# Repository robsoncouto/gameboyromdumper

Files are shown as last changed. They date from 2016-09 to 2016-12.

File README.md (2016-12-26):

# gbcart tool (in progress)
Tool for reading data from Game Boy cartridges or the Gameboy camera. The version in the first commits work(mar 2016), but I have started to clean the code, so the present version (dec 2016) is uncomplete. 
##Description
This is a project that I started in order to backup my Gameboy saves to the PC. It also dumps roms and Gameboy camera saves. All the process that lead to this program is detailed at www.dragaosemchama.com.br/?lang=en_us
##Hardware
Schematic and layout ealge files are available, the cartridge-PC interface board uses a atmega32 and a Gameboy Color cartridge socket. The socket was salvaged from a broken gameboy. The board is connected to a PC with a USB-serial ttl cable.
##Usage
The python script is used for reading saves, roms or the cartridge header. The microcontroller code was written for a Atmega32, but can be easily ported to other microcontrollers or architectures.
##Serial library
This code uses avr-uart library kindly shared by Andy Gock based on uart library code by Peter Fleury
https://github.com/andygock/avr-uart

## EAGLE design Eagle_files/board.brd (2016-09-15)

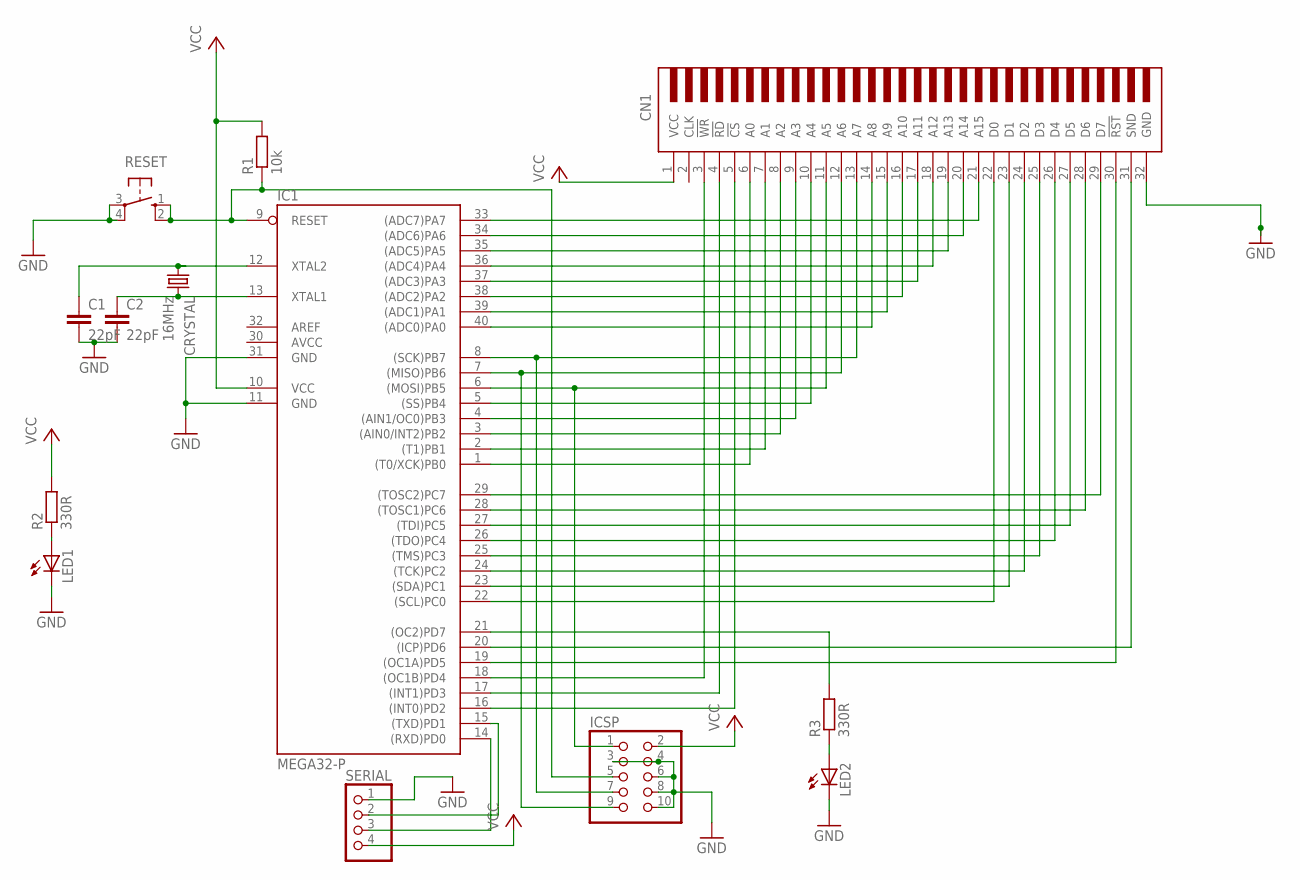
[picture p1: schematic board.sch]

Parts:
C1, C2: 22pF; C050-025X075
CN1: GBCONN
CRYSTAL: 16MHz; HC49/S
IC1: MEGA32-P; DIL40
ICSP: PINHD-2X5; 2X05
LED1, LED2: LED3MM
R1: 10k; 0204/7
R2, R3: 330R; 0204/7
RESET: 10-XX; B3F-10XX
SERIAL: PINHD-1X4/90; 1X04/90

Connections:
AVCC: IC1.30 (AVCC)
GND: C1.2, C2.2, CN1.32 (GND), IC1.11 (GND), IC1.31 (GND), ICSP.3, ICSP.4, ICSP.6, ICSP.8, ICSP.10, LED1.K (C), LED2.K (C), RESET.3, RESET.4 (P1), SERIAL.1
unnamed: CN1.29 (D7), IC1.29 ((TOSC2)PC7)
unnamed: CN1.28 (D6), IC1.28 ((TOSC1)PC6)
unnamed: CN1.27 (D5), IC1.27 ((TDI)PC5)
unnamed: CN1.26 (D4), IC1.26 ((TDO)PC4)
unnamed: CN1.25 (D3), IC1.25 ((TMS)PC3)
unnamed: CN1.24 (D2), IC1.24 ((TCK)PC2)
unnamed: CN1.23 (D1), IC1.23 ((SDA)PC1)
unnamed: CN1.22 (D0), IC1.22 ((SCL)PC0)
unnamed: CN1.21 (A15), IC1.33 ((ADC7)PA7)
unnamed: CN1.20 (A14), IC1.34 ((ADC6)PA6)
unnamed: CN1.19 (A13), IC1.35 ((ADC5)PA5)
unnamed: CN1.18 (A12), IC1.36 ((ADC4)PA4)
unnamed: CN1.17 (A11), IC1.37 ((ADC3)PA3)
unnamed: CN1.16 (A10), IC1.38 ((ADC2)PA2)
unnamed: CN1.15 (A9), IC1.39 ((ADC1)PA1)
unnamed: CN1.14 (A8), IC1.40 ((ADC0)PA0)
unnamed: CN1.13 (A7), IC1.8 ((SCK)PB7), ICSP.7
unnamed: CN1.12 (A6), IC1.7 ((MISO)PB6), ICSP.9
unnamed: CN1.11 (A5), IC1.6 ((MOSI)PB5), ICSP.1
unnamed: CN1.10 (A4), IC1.5 ((SS)PB4)
unnamed: CN1.9 (A3), IC1.4 ((AIN1/OC0)PB3)
unnamed: CN1.8 (A2), IC1.3 ((AIN0/INT2)PB2)
unnamed: CN1.7 (A1), IC1.2 ((T1)PB1)
unnamed: CN1.6 (A0), IC1.1 ((T0/XCK)PB0)
unnamed: CN1.30 (!RST), IC1.19 ((OC1A)PD5)
unnamed: CN1.4 (!RD), IC1.17 ((INT1)PD3)
unnamed: CN1.5 (!CS), IC1.16 ((INT0)PD2)
unnamed: LED1.A, R2.1
unnamed: CN1.31 (SND), IC1.20 ((ICP)PD6)
unnamed: C1.1, CRYSTAL.1, IC1.12 (XTAL2)
unnamed: C2.1, CRYSTAL.2, IC1.13 (XTAL1)
unnamed: CN1.3 (!WR), IC1.18 ((OC1B)PD4)
unnamed: LED2.A, R3.1
unnamed: IC1.21 ((OC2)PD7), R3.2
unnamed: IC1.9 (RESET), ICSP.5, R1.1, RESET.1 (S), RESET.2 (S1)
unnamed: IC1.15 ((TXD)PD1), SERIAL.2
unnamed: IC1.14 ((RXD)PD0), SERIAL.3
VCC: CN1.1 (VCC), IC1.10 (VCC), ICSP.2, R1.2, R2.2, SERIAL.4

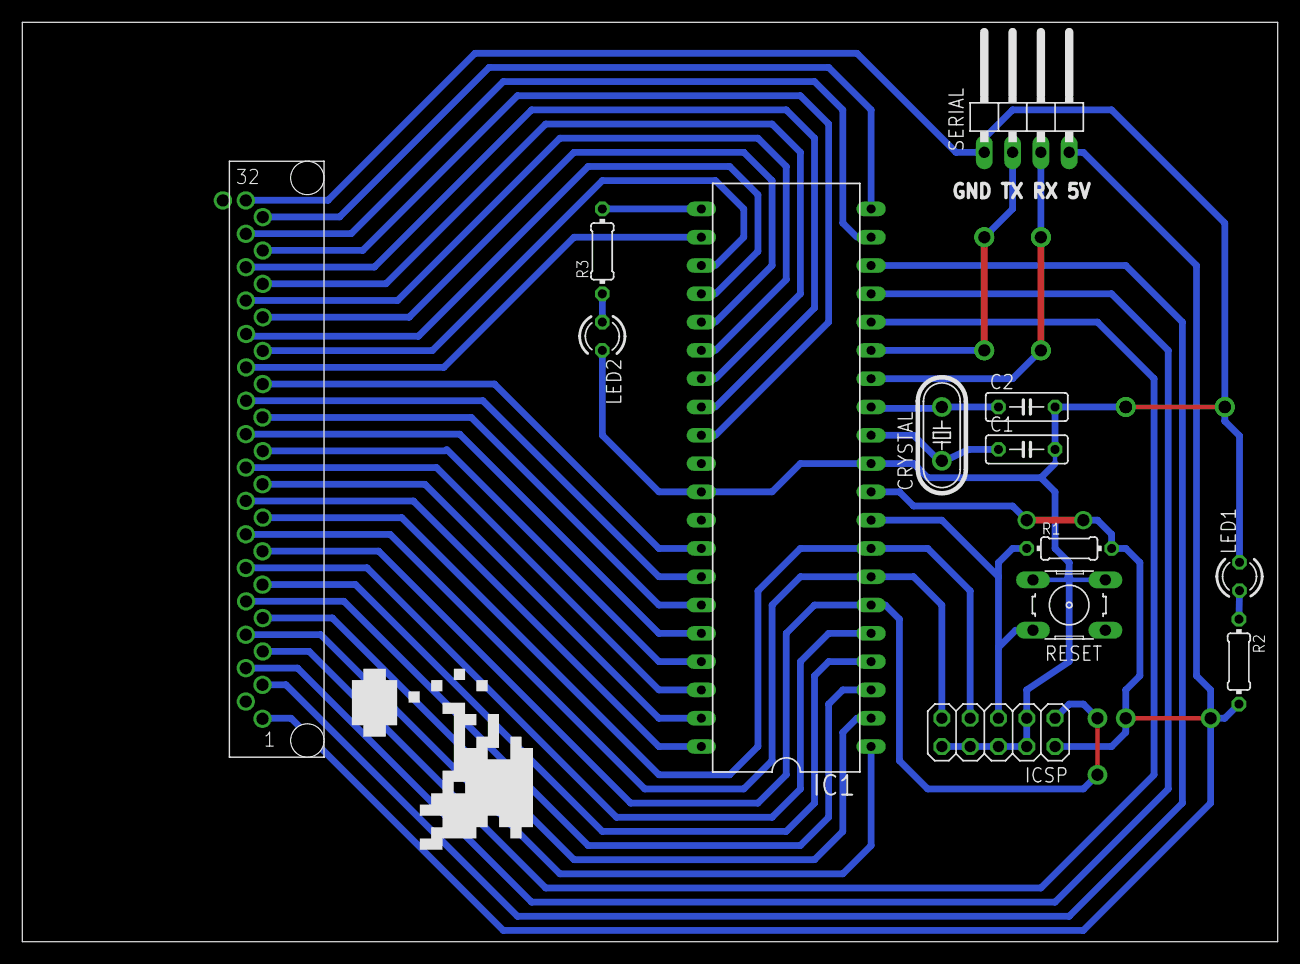
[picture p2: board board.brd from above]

Board: 2 copper layers, 112.7 x 82.5 mm, 13 parts (0 on the bottom side), 39 nets.

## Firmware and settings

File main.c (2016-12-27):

/*
 * GBCartReader.c
 *
 * Created: 29/10/2015 20:00:15
 *  Author: Roco
 */
#define F_CPU 16000000UL
#define UART_BAUD_RATE 38400


#include<avr/io.h>
#include<util/delay.h>
#include "serial/uart.h"
#include "gbcart.h"

uint8_t inByte=0,num=0,addrH=0,addrL=0;
uint16_t address;


int main(void){
	init();
	_delay_ms(2000);
	while(1){
		PORTD^=(1<<7);
		//uart_puts("Restart complete");
		if (uart_available()>2){
			while (uart_available()>0){
				inByte=uart_getc();
				if (inByte=='a'){
					inByte=uart_getc();
					if (inByte=='b'){
						inByte=uart_getc();
						switch (inByte){
							case 'c':
								readROM();
							break;
							case 'd':
								//prints the rom header information
								init();
								cartInfo();
							break;
							case 'r':
								// just runs the init() function again, this is important to set the right MBC
								init();
								uart_puts("Restart complete");
							break;
							case 'y':
								//Prints ram through serial
								readRAM();
							break;
							case 'k':
								//Not done yet .... work in progress
								while(uart_available()<2);
          			addrH=uart_getc();
								addrL=uart_getc();
          			writeBlock(RAM,addrH,addrL);
							break;
							case 'b':
								while(uart_available()<2);
								addrH=uart_getc();
								addrL=uart_getc();
								writeBlock(ROM,addrH,addrL);
							break;
							//puppet mode, work in progress
							case 'e':
								eraseflash();
							break;

							case 'f':
							//read bytes from location
								while(serialAvailable()<3);
								address = serialRead();
								address |= (serialRead()<<8);
								num=serialRead();
								//uart_puts("Byte: \n");
								while (num>0)
								{
									uart_putc(readByte(address++));
									num--;
								}
								uart_putc('\n');
							case 'g':
								while(serialAvailable()<3);
								address = serialRead();
								address |= (serialRead()<<8);
								num=serialRead();
								//uart_puts("Byte: \n");
								WriteByte(address,num);
								uart_putc(readByte(address));
								uart_putc('\n');
							break;
						}
					}
				}
			}

		}
	}
}

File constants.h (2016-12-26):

#ifndef CONSTANTS
#define CONSTANTS

#include<avr/io.h>

#define LED 7
#define CLK 7
#define SND 6
#define RST 5
#define WR 4
#define RD 3
#define MREQ 2
#define TX 1
#define RX 0


#define ControlPort PORTD
#define ControlDDR  DDRD

#define DATAOUT PORTC
#define DATAIN PINC
#define DATADDR DDRC

#define ADRH PORTA
#define ADRL PORTB

#define ADRHDDR DDRA
#define ADRLDDR DDRB

#endif

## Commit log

2016-09-15 Added ealge files
    [board.brd, board.sch]
2016-11-23 Fixed serial library location
    [main.c]
2016-12-19 removed compiled uart library
2016-12-21 Removing uart library from main...
2016-12-24 Fixed python script functions order
    [burn.py]
2016-12-24 Error checking for save upload seems to be workin. Needs more tests
    [burn.py, constants.h, gbcart.c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]
2016-12-24 A bug is crashing the board, probrably serial library, but yet to check
    [burn.py]
2016-12-25 See last commit. Aparently no software issue, there was a broken track in my board
    [burn.py, main.c]
2016-12-25 A problem in the board probrably caused a problem in the board. It took me much time to realise what was the problem, because I thought it was software. Now the serial link seems to be ok again
    [burn.py, gbcart.c, main.c]
2016-12-25 Added a small delay between calls to serial write. This stopped the board from glitching
    [burn.py]
2016-12-26 Bug in serial library, changed to updatep version by Andy Gock
    [gbcart.c, main.c]
2016-12-26 Fixed code for writing dat to RAM
    [gbcart.c]
2016-12-26 Fixed addres size for ROM
    [gbcart.c]
2016-12-27 There is data overlap in the code, probrably a problem with bank selecting
    [burn.py, gbcart.c, main.c]
2016-12-27 Fixed problem with ROM address size, but bugs still persist
    [gbcart.c]
